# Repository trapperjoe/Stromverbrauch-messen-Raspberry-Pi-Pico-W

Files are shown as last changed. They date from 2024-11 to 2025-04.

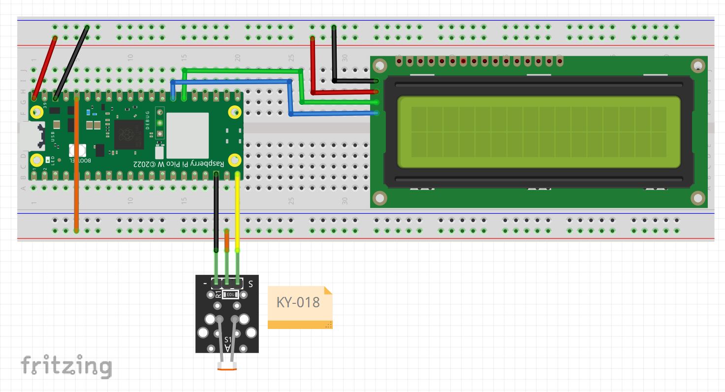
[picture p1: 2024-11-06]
Stromverbrauchsmessung.JPG

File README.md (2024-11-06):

Vor kurzem stand ich vor folgender Problemstellung: 
Mein Stromverbrauch ist (gefühlt) zu hoch und ich wollte der Sache auf den Grund gehen und "Stromfresser" finden und eliminieren. 

Dazu wollte ich meinen aktuellen Stromverbrauch einfach nur ablesen aber mein Stromverbrauchszähler im Keller ist schon älter und sendet nur Lichtimpulse und 
zwar umso schneller, je mehr Strom fließt.  Leider ist mein Stromverbrauchszähler nicht "smart", so dass es keine Möglichkeit gibt, dass er weitere Messdaten 
liefern oder anzeigen kann, weder optisch noch elektrisch. Man kann lediglich die Zählerdaten ablesen, nicht aber den momentanen "Verbrauch". 

Was tun ?
Natürlich kann man mit  einer Stoppuhr daneben stehen und die Zeitdauer zwischen zwei Impulsen messen. Diese dann aufschreiben und später ausrechnen, welcher momentanen  
Leistung dies entspricht. Das ist aber kein flexibles Verfahren, zudem sehr ungenau. 

Eine bessere Lösung ist es mit einer kleinen elektronischen Schaltung die Dauer zwischen zwei Impulsen zu messen, diese in einen momentanen Leistungswert umzurechnen und 
dann anzuzeigen. 

Auf meinem Stromverauchszähler steht, dass er pro kWh 1000 Impulse liefert. 
Beispiel:
Bei einer (angenommenen) Periode von 10 Sekunden zwischen zwei benachbarten Impulsen sind das 6 Impulse pro Minute und damit 360 Impulse pro Stunde. 
Das entspricht also einer momentanen Leistung von 360 Watt. 
Bei einer (angenommenen) Periode von 1 Sekunde zwischen zwei benachbarten Impulsen sind das 60 Impulse pro Minute und damit 3600 Impulse pro Stunde. 
Das entspricht also einer momentanen Leistung von 3600 Watt. 

Die Zeitmessung auf dem Raspberry Pi Pico W sollte sinnvollerweise in Millisekunden erfolgen. 
Daher lautet die Formel für die Umrechnung. 

Pm = 3600000 / Tp 

wobei Pm die momentane Leistung in Watt ist und Tp die Periodendauer in Millisekunden zwischen zwei benachbarten Impulsen.

Bei der hier vorgestellten Lösung erzeugt jeder Lichtimpuls einen Interrupt auf dem Rapsberry Pi Pico W. 
Die Interruptroutine ermittelt die Dauer zwischen zwei benachbarten Impulsen und speichert diese in einer globalen Variablen.  
Die Berechnung der Momentanleistung und die Anzeige der Werte bzw. Weiterleitung an den MQTT-Broker geschieht dann im Hauptprogramm.

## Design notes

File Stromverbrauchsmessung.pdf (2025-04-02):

# Stromverbrauchsmessung

# mit einem Raspberry Pi Pico W

# Funktionsweise

- Ein Lichtimpuls am Stromzähler löst einen Interrupt auf dem angeschlossenen Raspi Pico aus.
- Eine Routine auf dem Rapberry Pi Pico ermittelt die zeitliche Dauer zwischen zwei aufeinanderfolgenden Impulsen und speichert diese in einer globalen Variable.
- Der momentane Stromverbrauch ist indirekt proportional zu dieser Dauer. D.h. wenn sich z.B. die Zeitdauer zwischen zwei Impulsen verdoppelt, dann ist der momentane Stromverbrauch nur halb so groß!
- Im Hauptprogramm wird der Stromverbrauch ausgerechnet , auf dem Display dargestellt und zusätzlich an den MQTT-Broker geschickt.
- Der MQTT-Broker ist ein Modul, welches auf einem Raspberry Pi läuft als Add-On zu der dort installierten NodeRed Software.
- Wenn man nur die momentane Leistung auf dem Display ablesen will, dann benötigt man keinen MQTT-Broker und auch kein Netzwerk. Ebenso reicht dann auch ein einfacher Raspberry Pi Pico (ohne ‚W‘), sowie einen Fotowiderstand und ein Display. Das kostet dann zusammen weniger als € 30,-- und ist in weniger als einer Stunde aufgebaut.

# Hardware Aufbau

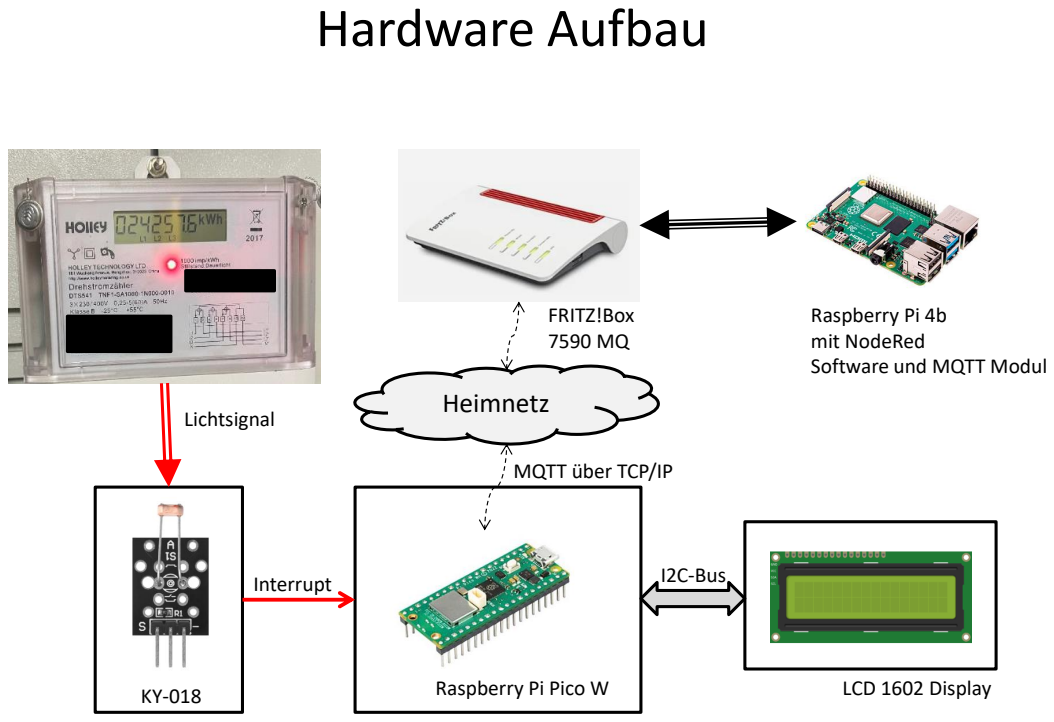
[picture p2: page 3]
Heimnetz Lichtsignal; Raspberry Pi Pico W; Interrupt; FRITZ!Box 7590 MQ; LCD 1602 Display; I2C-Bus

Raspberry Pi 4b
mit NodeRed
Software und MQTT Modul

MQTT über TCP/IP

# Bilder

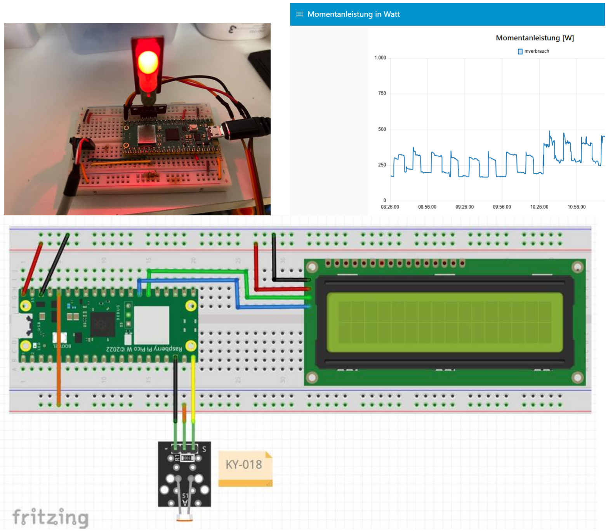
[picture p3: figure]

# Software: NodeRed

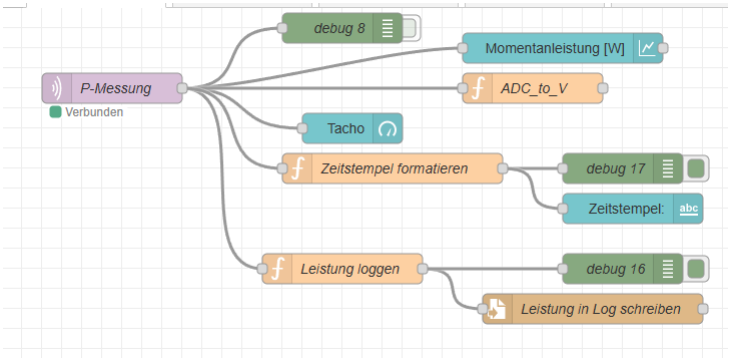
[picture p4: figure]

# Software: MicroPython

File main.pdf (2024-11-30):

### 1. Signalverarbeitung über GPIO15

Ziel:
Erfassung von Signalflanken (steigend/fallend) und Berechnung der Zeitdifferenz zwischen fallenden Flanken zur Bestimmung des momentanen Verbrauchs.

Interrupt-Routine: Signal_INT()

- Wird bei jeder Signaländerung (steigende/fallende Flanke) ausgelöst:
- Steigende Flanke:
- Speichert den Zeitpunkt (tck1).
- Aktiviert die onboard-LED.
- Fallende Flanke:
- Speichert den Zeitpunkt (tck2).
- Berechnet die Periode:

periode = tck2 - tck2_v

- Aktualisiert den Zähler icounter.

Flankendetektion:

- GPIO15 als Eingang mit Pull-Down konfiguriert:

Signal = machine.Pin(15, machine.Pin.IN, machine.Pin.PULL_DOWN)
Signal.irq(trigger=machine.Pin.IRQ_RISING | machine.Pin.IRQ_FALLING,
handler=Signal_INT)

### 2. Leistungsberechnung

Formel:

Die Leistung wird aus der Dauer der Periode berechnet:

Leistung (W) = 3600000 / periode

Anwendung:

- Berechnete Werte werden auf dem LCD angezeigt:

disp_lcd(str(counter), str(mverbrauch))

- Anschließend wird der Wert an einen MQTT-Broker gesendet.

### 3. WLAN-Verbindung

Die Funktion wlanConnect() stellt eine Verbindung zu einem WLAN her, indem SSID und Passwort aus einer privaten Datei geladen werden.

Details:

- Verbindungsaufbau:

wlan.connect(wlanSSID, wlanPW)

- LEDs (Gelb/Onboard) zeigen den Verbindungsstatus an.
- Bei Erfolg: Anzeige der IPv4-Adresse.
- Bei Misserfolg: Neustart des Prozesses.

### 4. MQTT-Integration

Verbindung herstellen: mqttConnect()

Stellt eine Verbindung zu einem MQTT-Broker mit Authentifizierung her:

client = MQTTClient(mqttClient, mqttBroker, user=mqttUser, password=mqttPW, keepalive=60)
client.connect()

Daten senden:
Die berechnete Leistung wird an das Topic mpower gesendet:

client.publish(mqttTopic0, myValue0)

- Nach dem Senden wird die Verbindung getrennt.
- Bei Fehlern wird der Mikrocontroller zurückgesetzt.

### 5. LEDs und LCD-Anzeige

LEDs:

- Rot/Gelb: Blinken zur Anzeige der Hauptaktivität.
- Grün: Zeigt erfolgreiche Verbrauchsberechnungen.

LCD:

- Ausgabe der Berechnungen auf einem 16x2-LCD über I2C:

disp_lcd(z1, z2)

### 6. Hauptschleife

- Funktionen:
- Berechnung der Leistung, Anzeige auf dem LCD und Übertragung via MQTT.
- Blinken der LEDs während des Wartens.
- Neustart: Nach 10.000 Interrupts oder bei Fehlern wird der Mikrocontroller zurückgesetzt.

Zusammenfassung

Der Code bietet:

1. Signalverarbeitung: Zeitmessung und Verbrauchsberechnung basierend auf GPIO-Signalen.
2. Netzwerkfähigkeit: Verbindung zu einem WLAN und einem MQTT-Broker.
3. IoT-Funktionalität: Übertragung der Verbrauchsdaten an einen entfernten Server.

Ideal für IoT-Projekte wie Energieüberwachung oder Verbrauchsmessung.

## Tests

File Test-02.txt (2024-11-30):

Der Code implementiert ein Programm für einen Mikrocontroller (z. B. Raspberry Pi Pico W) in MicroPython. 
Es analysiert Signaleingänge, berechnet zeitliche Intervalle zwischen Signaländerungen und leitet daraus den momentanen Verbrauch ab. 
Eine Anzeige und LEDs werden für die Visualisierung genutzt.

Ablauf und Funktionen
GPIO15-Signalüberwachung:

GPIO15 erkennt steigende (HIGH) und fallende (LOW) Flanken.
Ein Interrupt (Signal_INT) wird bei jedem Signalwechsel ausgelöst.

Zeitmessung:
Bei steigender Flanke: Speichert tck1 (Zeitstempel).
Bei fallender Flanke: Speichert tck2 (Zeitstempel) und berechnet die Dauer (periode) zwischen den letzten beiden fallenden Flanken.

Leistungsberechnung:
Die Leistung PPP wird aus der Periode berechnet: P=3600000/periode [Watt] 

Anzeige und LEDs:
Ergebnis wird auf einem LCD (I2C) dargestellt.
LEDs signalisieren Status:
Rot/Gelb blinken für Aktivitäten.
Grün zeigt, dass eine Berechnung erfolgt ist.

Hauptprogramm:
Endlosschleife zählt counter.
Signaländerungen werden erfasst, Zeitintervalle berechnet und aufbereitet.

Reset:
Nach 10.000 Iterationen wird der Mikrocontroller zurückgesetzt.
Wichtige Funktionen
Interrupt-Routine: Signal_INT()
Steuert die Reaktion auf Signaländerungen:
Steigende Flanke: Speichert Startzeit (tck1) und schaltet die LED ein.
Fallende Flanke: Berechnet die Zeitspanne zwischen zwei fallenden Flanken und speichert sie in periode.
Anzeige: disp_lcd(z1, z2)
Zeigt Zähler und berechnete Leistung auf dem LCD an.

Hauptschleife:
Berechnet und zeigt die Leistung in der Schleife, wenn periode gültig ist:

python
if (counter > 1) and (periode > 0):
    mverbrauch = int(3600000 / periode)
    disp_lcd(str(counter), str(mverbrauch))
Zusammenfassung
Der Code dient zur Überwachung eines Signals, Berechnung des momentanen Verbrauchs und Anzeige der Ergebnisse. 
LEDs und LCD unterstützen die Visualisierung der laufenden Prozesse.

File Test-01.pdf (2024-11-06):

Detaillierte (KI generierte) Erklärungen des Programmcodes von Test-01.py

Dieser Python-Code überwacht ein GPIO-Signal und registriert Änderungen des Signalstatus, indem er einen Interrupt-Handler verwendet. Der Code läuft auf Mikrocontroller-Plattformen wie dem Raspberry Pi Pico oder ähnlichen Geräten.

Hier eine Erklärung des Codes:

### Überblick

- Der Code verwendet das Modul `machine` für GPIO-Operationen und `utime` für die Zeitmessung
- Eine LED auf dem Board wird als Statusanzeige verwendet.
- Ein Interrupt-Handler registriert Statusänderungen an einem bestimmten GPIO-Pin (GPIO15) und protokolliert die Zeiten, zu denen das Signal an- und ausgeht, um die Dauer der Signale zu messen.

### Erklärungen der Codeabschnitte

1. **Importierte Module**:

```python
from machine import Pin
import utime
```

Diese Module werden verwendet, um die GPIO-Pins zu steuern und Zeitstempel zu erzeugen.

2. **LED-Steuerung**:

```python
led_onboard = machine.Pin('LED', machine.Pin.OUT, value=0)
```
Hier wird die Onboard-LED als `Pin`-Objekt definiert, das als Ausgang genutzt wird und initial auf `AUS` (Wert `0`) gesetzt ist.

3. **Interrupt-Handler `Signal_INT`**:

```python
def Signal_INT(pin):
```
- Wird aufgerufen, wenn sich der Signalzustand ändert.
- Deaktiviert den Interrupt-Handler kurzzeitig mit `Signal.irq(handler=None)`, um zu verhindern, dass er während der Verarbeitung erneut aufgerufen wird.
- Erkennt, ob das Signal von `AUS` auf `AN` oder von `AN` auf `AUS` wechselt, und führt entsprechende Aktionen aus:
- Bei `AN`
- Setzt `Signal_Status` auf 1.
- Schaltet die LED ein.
- Speichert die aktuelle Zeit in `tck1`.
- Bei `AUS`
- Setzt `Signal_Status` auf 0.
- Schaltet die LED aus.
- Speichert die aktuelle Zeit in `tck2`.
- Berechnet die Periodendauer, falls `tck2_v` gesetzt ist.
- Aktiviert den Interrupt-Handler wieder am Ende.
4. **GPIO-Konfiguration**:

```python

Signal = machine.Pin(15, machine.Pin.IN, machine.Pin.PULL_DOWN)

Signal.irq(trigger=machine.Pin.IRQ_RISING | machine.Pin.IRQ_FALLING, handler=Signal_INT)

```

Der Pin 15 wird als Eingang mit Pull-Down-Widerstand konfiguriert. Der Interrupt-Handler wird so
eingestellt, dass er bei steigenden und fallenden Flanken (`IRQ_RISING | IRQ_FALLING`) ausgelöst
wird.

5. **Initialisierung der Variablen**:

```python
Signal_Status = Signal.value()
tck1 = 0; tck2 = 0; tck2_v = -1; periode = -1

```

Die Variablen werden initialisiert, um Signalstatus und Zeitstempel zu speichern.

6. **Hauptschleife**:

```python
while True:
print("counter = ", counter, "\t Pulsdauer = ", tck2-tck1, 'ms') utime.sleep(2)
counter += 1
```
Eine Endlosschleife, die alle 2 Sekunden eine Ausgabe der aktuellen Zählvariable und der Pulsdauer ausgibt. Hier könnten weitere Aktivitäten hinzugefügt werden.

### Zusammenfassung

Der Code dient zur Überwachung von Signalen an einem GPIO-Pin und zur Messung der Zeit zwischen Signaländerungen. Dies könnte in Anwendungen wie Taktmessungen oder Erkennung von Signalpulsen nützlich sein.

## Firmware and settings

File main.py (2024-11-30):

# In diesem Programm löst ein Signal am Eingang des GPIO15
# einen Interrupt aus. Dabei wird jede Statusänderung erfasst, d.h. 
# sowohl eine steigende als auch eine fallende Flanke bewirken
# den Aufruf der selben Interruptroutine aus (Funktion: Signal_INT()). 
# Bei einer fallende Flanke wird die aktuelle Zeit ermittelt und
# anschließend die zeitliche Differenz zu der davor aufgetretenen,
# fallenden Flanke errechnet. 
# Diese Dauer (periode) ist ein Maß für den momentanen Verbrauch.
# Je größer die Dauer, um so kleiner ist der Verbrauch. 
# Der momentane Verbrauch (mverbrauch) wird dann am Display angezeigt.
# Die interne LED blinkt kurz bei jedem Aufruf der Interruptroutine.
#
#
# Bibliotheken laden
from machine import I2C, Pin, reset
from machine_i2c_lcd import I2cLcd
from simplep import MQTTClient
import network
import utime
from _JM_priv import wlan_SSID, wlan_PW
from _JM_priv import IP_mqtt_broker, mqtt_Client, mqtt_User, mqtt_PW

# Status-LED onboard
led_onboard = machine.Pin('LED', machine.Pin.OUT, value=0)
#
# Definition of LEDs
rled 	= machine.Pin(10, machine.Pin.OUT)
yled 	= machine.Pin(11, machine.Pin.OUT)
gled 	= machine.Pin(12, machine.Pin.OUT)

# WLAN-Access und MQTT-Broker-Details
wlanSSID 	= wlan_SSID()
wlanPW 		= wlan_PW()

# MQTT-Konfiguration
mqttBroker 	= IP_mqtt_broker()
mqttClient 	= mqtt_Client()
mqttUser 	= mqtt_User()
mqttPW 		= mqtt_PW()
mqttTopic0 	= b"mpower"


def disp_lcd(z1, z2):
    # Ausgabe auf Display             
    zeile_1  = " Counter: " + str(z1) + '\n'
    zeile_2  = "Leistung: " + str(z2) + 'W \n'  
    try:
        lcd.clear()
        lcd.putstr(zeile_1)
        utime.sleep(0.2)
        lcd.putstr(zeile_2)
        utime.sleep(0.2)
    except:
        print("Z054")
    return

# Function: Connect to WLAN
def wlanConnect():
    yled.value(1); utime.sleep(2); yled.value(0)
    wlan = network.WLAN(network.STA_IF)
    if not wlan.isconnected():
        print('WLAN-Verbindung herstellen:', wlanSSID)
        wlan.active(True)
        wlan.connect(wlanSSID, wlanPW)
        for i in range(10):
            if wlan.status() < 0 or wlan.status() >= 3:
                break
            led_onboard.toggle()
            print('.')
            utime.sleep(1)

    if wlan.isconnected():
            print('WLAN-Verbindung hergestellt / WLAN-Status:', wlan.status())
            ipconfig = wlan.ifconfig()
            print('IPv4-Adresse:', ipconfig[0])
            led_onboard.on()
            yled.value(1)
    else:
        print('Keine WLAN-Verbindung / WLAN-Status:', wlan.status())
        print()
        led_onboard.off()
        yled.value(0)

# Funktion: Verbindung zum MQTT Server herstellen
def mqttConnect():
    if mqttUser != '' and mqttPW != '':
        print("MQTT-Verbindung herstellen: %s mit %s als %s" % (mqttClient, mqttBroker, mqttUser))
        client = MQTTClient(mqttClient, mqttBroker, user=mqttUser, password=mqttPW, keepalive=60)
    client.connect()
    print('MQTT-Verbindung hergestellt')
    return client


def Signal_INT(pin):          # Signal Interrupt handler
    global Signal_Status      # Bezug zur globalen Variablen
    global tck1, tck2, tck2_v, periode
    global icounter
    
    Signal.irq(handler=None)  # Abschalten während der Ausführung 
    
    if icounter >= 10000:
        reset()
    
    if (Signal.value() == 1) and (Signal_Status == 0):
        # Steigende Flanke 
        Signal_Status = 1     	# Setze Signal_Status auf HIGH
        led_onboard.value(1)    # Schalte LED_onboard ein
        tck1 = utime.ticks_ms() # Ermittle und speichere Zeitpunkt
        # print()
        # print("High tck1 = ", tck1, ' ms')
            
    elif (Signal.value() == 0) and (Signal_Status == 1):
        # Fallende Flanke
        Signal_Status = 0     	# Setze Signal_Status auf LOW
        led_onboard.value(0)    # Schalte LED_onboard aus
        tck2 = utime.ticks_ms() # Ermittle und speichere Zeitpunkt
        # print("Low  tck2 = ", tck2, ' ms')
        ## print("tck2_v = \t", tck2_v, '\t', "tck2 = \t", tck2)
        
        if tck2_v > 0:
            periode = tck2 - tck2_v
            # periode ist die Dauer zwischen zwei fallenden Flanken
            print("Periode = ", periode)
        tck2_v = tck2   # speichere tck2 für den nächsten Aufruf 
        icounter = icounter + 1
        print("icounter = ", icounter )
    Signal.irq(handler=Signal_INT) # aktiviere die Interruptroutine
    

# Definiere ein "Objekt" für den Statuswechsel des Signals
Signal = machine.Pin(15,machine.Pin.IN,machine.Pin.PULL_DOWN)
# Definition des Interrupthandlers für den Statuswechsel des Signals
Signal.irq(trigger=machine.Pin.IRQ_RISING | machine.Pin.IRQ_FALLING, handler=Signal_INT)


# Setze die Status Variable für das Signal
Signal_Status = Signal.value()
print("Signal Status: ", Signal_Status)

# Start des Hauptprogramms
# Initialisierung I2C
i2c = I2C(0, sda=Pin(20), scl=Pin(21), freq=100000)

# Initialisierung LCD über I2C
lcd = I2cLcd(i2c, 0x27, 2, 16)

tck1 = 0; tck2 = 0; tck2_v = -1; periode = -1
print("Start...... !")
wlanConnect()

counter = 0; icounter = 0
while True:
    counter += 1
    rled.value(1); yled.value(0); utime.sleep(2)
    rled.value(0); yled.value(1); utime.sleep(2)    
   
    if (counter > 1) and (periode > 0):
        try:
            mverbrauch = int(3600000 / periode)
            ## print("Messung: \t", counter, "\tPeriode: \t", periode, '\t ms',"Leistung: \t", mverbrauch, '\t W')
            print("Nr: \t", counter,"\t Leistung: \t", mverbrauch, '\t W')
            rled.value(0); yled.value(0); gled.value(1); utime.sleep(0.5)
            disp_lcd(str(counter), str(mverbrauch))
            rled.value(0); yled.value(0); gled.value(0); utime.sleep(0.5)
 
 
        except:
            print("Z168")
            reset()

        myValue0 = str(mverbrauch)
        try:
            client = mqttConnect()
            client.publish(mqttTopic0, myValue0)
            print("An Topic %s gesendet: %s" %  (mqttTopic0, myValue0))
            utime.sleep(1)

            client.disconnect()
            print('MQTT-Verbindung beendet \n')

        except OSError:
            print("Z182")
            print('Fehler: Keine MQTT-Verbindung')
            print()
            reset()
          
    else:
        print("Waiting... \r", end = '')
    

# Hier können weitere Aktivitäten erfolgen !!

#######################################################################################

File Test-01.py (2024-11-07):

# Dieses Programm erwartet einen Impuls auf dem GPIO15 
# Es reagiert dabei auf jeden Statuswechsel, d.h. sowohl auf eine steigende Flanke,
# alsauch auf eine fallende Flanke des Impulses 
# Initial wird der Signalpegel als "LOW" angenommen.
# Eine steigende Flanke wird dann als ein Wechsel von LOW zu HIGH definiert. 
# Ebenso ist dann definitionsgemäß eine fallende Flanke ein Wechsel von HIGH auf LOW. 
# 
# Während der HIGH Phase des Impulses wird die interne LED eingeschaltet,
# ansonsten bleibt sie ausgeschaltet.
#
# Wenn eine steigende Flanke erkannt wurde, dann wird die globale Variable tck1
# mit einem Zeitstpempel gesetzt. Eine fallende Flanke setzt dann die Variable tck2
# mit einem weiteren Zeitstempel. 
# Die Differenz der beiden Zeitstempel (tck2 - tck1) ist dann die Impulsdauer. 
# 
#
# Bibliotheken laden
from machine import Pin
import utime

# Status-LED onboard (für Raspberry Pico W)
led_onboard = machine.Pin('LED', machine.Pin.OUT, value=0)

# Signal Interrupt Handler
def Signal_INT(pin): 
    global Signal_Status 				# Signal_Status gibt den aktuellen Pegel des Impulses an
    global tck1, tck2, tck2_v, periode	# globale Variablen für die Zeitermittlung
 
    Signal.irq(handler=None)  			# Interrupt Handler abschalten während der Ausführung 
    
    if (Signal.value() == 1) and (Signal_Status == 0):
    # Signal ist jetzt aktiv (HIGH) war aber vorher auf LOW, d.h. es wurde
    # eine steigende Flanke erkannt !

        Signal_Status = 1     					# Setze Signal_Status auf HIGH
        led_onboard.value(1)    				# Schalte LED_onboard ein
        tck1 = utime.ticks_ms()					# Setze globale Variable tck1 mit einem aktuellen Zeitstempel
        print()
        print("High tck1 = ", tck1, ' ms')		# Gebe den Wert von tck1 aus
            
    elif (Signal.value() == 0) and (Signal_Status == 1):
    # Signal ist jetzt nicht aktiv (LOW) war aber vorher auf HIGH, d.h. es wurde
    # eine fallende Flanke erkannt !

        Signal_Status = 0     					# Setze Signal_Status auf LOW
        led_onboard.value(0)    				# Schalte LED_onboard aus
        tck2 = utime.ticks_ms()					# Setze globale Variable tck2 mit einem aktuellen Zeitstempel
        print("Low  tck2 = ", tck2, ' ms')		# Gebe den Wert von tck2 aus
        
        ## print("tck2_v = \t", tck2_v, '\t', "tck2 = \t", tck2)
        if tck2_v > 0:				# tck2_v ist der vorherige Wert von tck2 beim letzten Aufruf
            periode = tck2 - tck2_v	#  periode gibt die Zeitdifferenz zwischen zwei fallenden Flanken an
            ## print("periode = ", periode, 'ms')
        tck2_v = tck2    			# Setze die Variable tck2_v auf den Wert von tck2 für den nächsten Aufruf
    
    Signal.irq(handler=Signal_INT)	# Interrupt Handler wieder einschalten
    

# Definiere ein "Objekt" für den Statuswechsel des Signals
Signal = machine.Pin(15,machine.Pin.IN,machine.Pin.PULL_DOWN)
# Definition des Interrupthandlers für den Statuswechsel des Signals
Signal.irq(trigger=machine.Pin.IRQ_RISING | machine.Pin.IRQ_FALLING, handler=Signal_INT)



# Start des Hauptprogramms

# Setze die Status Variable für das Impulssignal
Signal_Status = Signal.value() 			# Signal_Status sollte anfänglich auf LOW gesetzt sein
                                        # wegen dem internen PULLDOWN Befehl auf GPIO15 
print("Signal Status: ", Signal_Status)	# Gib zur Überprüfung den initialen Zustand von Signal_Status aus


counter = 0								# Setze den Schleifenzähler initial auf 0
tck1 = 0; tck2 = 0; tck2_v = -1; periode = -1 # Setze die globalen Variablen tck2_v und periode auf ungültige Werte, 
                                        # da diese erst später im Signal Interrupt Handler gesetzt werden
print("Start...... !")
while True:								# Endlos Scheife
    # Gib den Schleifenzähler (counter) und die Impulsdauer aus
    print("counter = ", counter, "\t Pulsdauer = ", tck2-tck1, 'ms')
    utime.sleep(2)						# Warte ein wenig....
    counter += 1						# Erhöhe den Schleifenzähler
        
# Hier können weitere Aktivitäten erfolgen !!
#    
#
#######################################################################################

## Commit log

2024-11-07 Update Test-01.py
    Added some comments and typos corrected!
    [Test-01.py]
2025-04-02 Create Zeitstempel_formatieren
    Eine kleie Javascript Funktion, die einen Zeitstempel im gewohnten (europäischen) Format erstellt.
    Beispiel: 31.032025 09:21:45
2025-04-02 Create Leistung_loggen
    Kleiner Function Node um die Leistungsdaten aufzubereiten.
2025-04-02 Create ADC_to_V
    Kleiner Function Node um den ADC Wert am Pico in eine Spannung umzuwandeln.
2025-04-02 Create ADC_to_V
    Umwandlung ADC Wert am Pico in Volt.
2025-04-02 Create Zeitstempel_formatieren
    Kleine Funktion in Javascript, die eine Zeit im gewohnten (europ.) Format darstellt.
    Beispiel: 31.03.2025 08:15:03
2025-04-02 Create Zeitstempel formatieren
    Kleine Funktion, die die Zeit im gewohnten (europ.) Format darstellt.
    Beispiel:
    31.03.2025 08:07:12
